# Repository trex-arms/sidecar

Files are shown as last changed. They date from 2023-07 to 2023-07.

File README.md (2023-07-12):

# T.REX ARMS Sidecar Project

The [T.REX ARMS Sidecar Holster](https://www.trex-arms.com/store/trex-arms-sidecar-holster/) is designed to be modular and extendable.  This repository contains resources that should be enough for anyone to design, manufacture, and sell their Sidecar accessories.  These files are licensed under the [MIT license](https://choosealicense.com/licenses/mit/).

## [Spine System](Spine)

The T.REX ARMS Sidecar hinges on its Spine System.  The Sidecar Spine System was developed with open-source capabilities in mind, since the Spine System is a design that combines the best aspects of both rigid and flexible Sidecar-style holsters. It allows rotation on one axis, which provides comfort, but is extremely rigid on all others, for better concealment. Furthermore, the integrated hinge is simpler, sleeker, and far more modular than other existing connector options.

The design is built around as many off-the-shelf tools and parts as possible, both to support end users and other manufacturers. For example, the hinge pin has a diameter of 0.25″ and the hinge teeth are 0.25″ with 0.25″ gaps. Individual Kydex attachments can be made with hand tools, and the Spine also interfaces well with plastic parts, like the [T.REX Raptor Wing](https://www.trex-arms.com/store/sidecar-raptor-wing-attachment/), or certain textiles, like the biothane [T.REX Tourniquet Holder](https://www.trex-arms.com/store/sidecar-tourniquet-attachment/).

Included are some prints showing all the dimensions in the Sidecar Spine standard that our holsters will be held to, and some 3D files of different tools used in holster manufacture.

## Accessories

We have had excellent results printing these accessories using PLA+ filament on FDM printers like the Ender 3, eSUN’s Hard-Tough resin on SLA printers like the Elgoo Mars line, and having them printed in nylon by professional printers like MK Machining.

### [Dual Wield Adapter](DualWieldAdapter)

If you would like to carry and fire two guns whilst jumping through the air, you would need two sidecar holsters connected together with exactly the right amount of separation for pistol optics and exactly the right amount of angle for a quick draw.

### [Extender](Extender)

One of the best ways to expand your Sidecar’s comfort and concealability might be to literally expand its width. A number of users have discovered that extending the distance between the holster and mag carrier can improve comfort and stability for certain body types.

Since there are many different ways in which you might want to do this, we're including three different widths of file type, as well as a few previous versions.

If you make one of these, you will also need an additional pin to assemble it. The Sidecar Spine System will work with almost any 0.25” rod, including standard hinge pins, but you can get extras from us [here](https://www.trex-arms.com/store/sidecar-spine-replacement-hardware/).

### [Wing](Spine/Wing)

You know, [one of these](https://www.trex-arms.com/store/sidecar-raptor-wing-attachment/). But there's also an angled one that lets you fold the clips back over the holster for a smaller footprint. These wings are also the ideal starting point for any new adapters designed to connect the spine system to any mounting hardware.

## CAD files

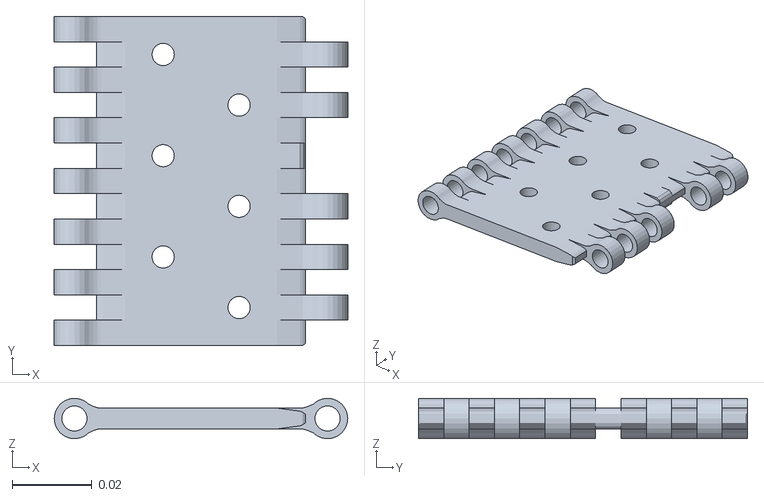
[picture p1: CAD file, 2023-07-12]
Extender/FullExtender25.stl
0.0737 x 0.0826 x 0.0102

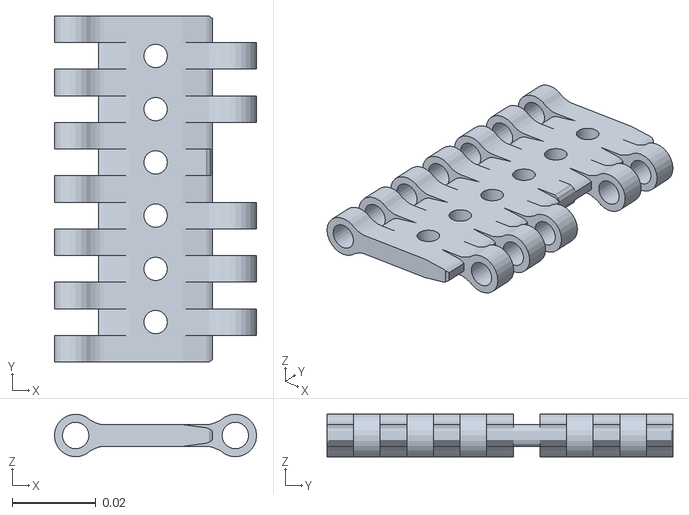
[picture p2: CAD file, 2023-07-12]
Extender/FullExtender15.stl
0.0483 x 0.0826 x 0.0102

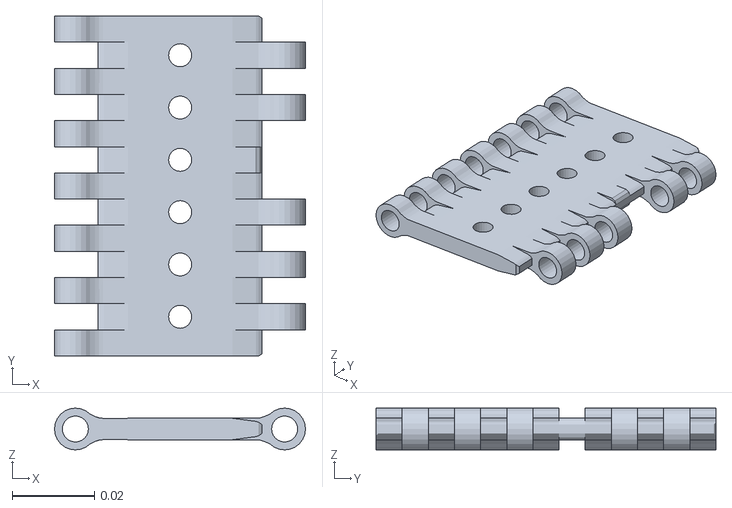
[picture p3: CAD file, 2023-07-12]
Extender/FullExtender20.stl
0.061 x 0.0826 x 0.0102

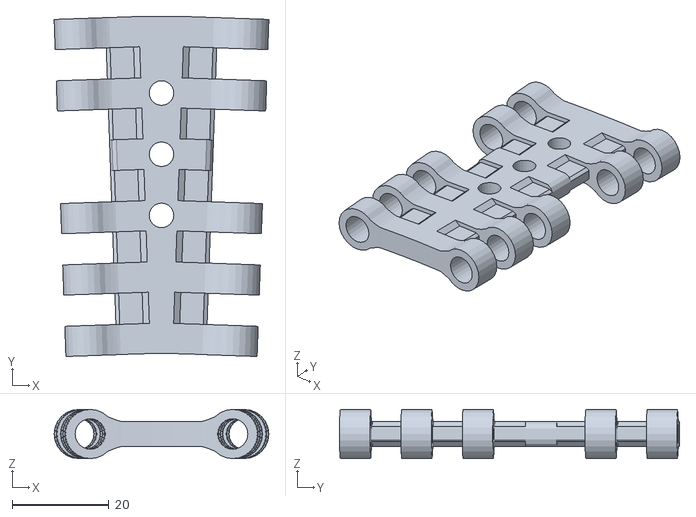
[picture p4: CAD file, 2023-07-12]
DualWieldAdapter/DualWieldAdapterV2.stl
44.4 x 70.3 x 10.2

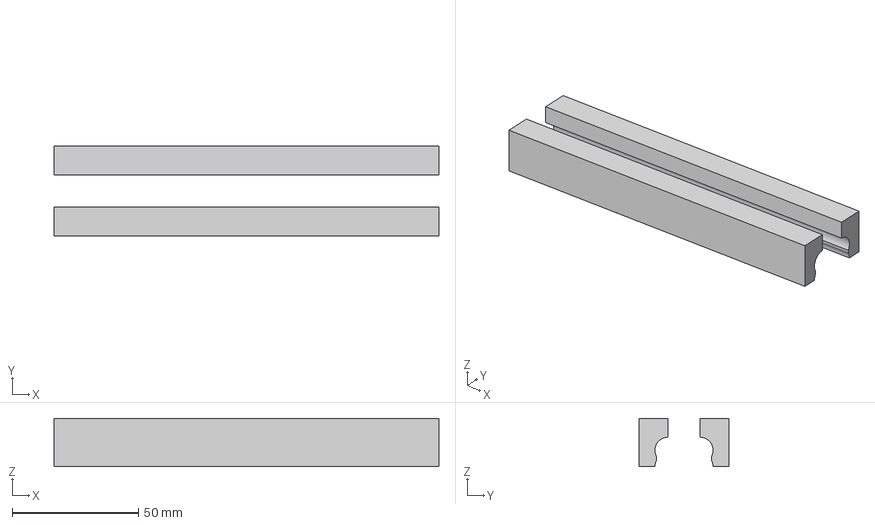
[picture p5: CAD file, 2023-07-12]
Spine/Sidecar Spine Clamp Halves.step
152.4 x 35.7 x 19.0 mm

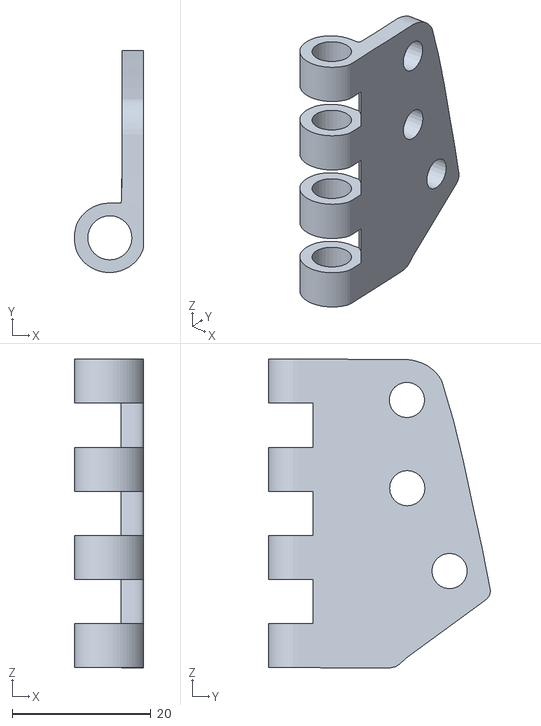
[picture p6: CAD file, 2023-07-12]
Spine/Wing/SidecarAngledWing.stl
10.0 x 32.0 x 44.5

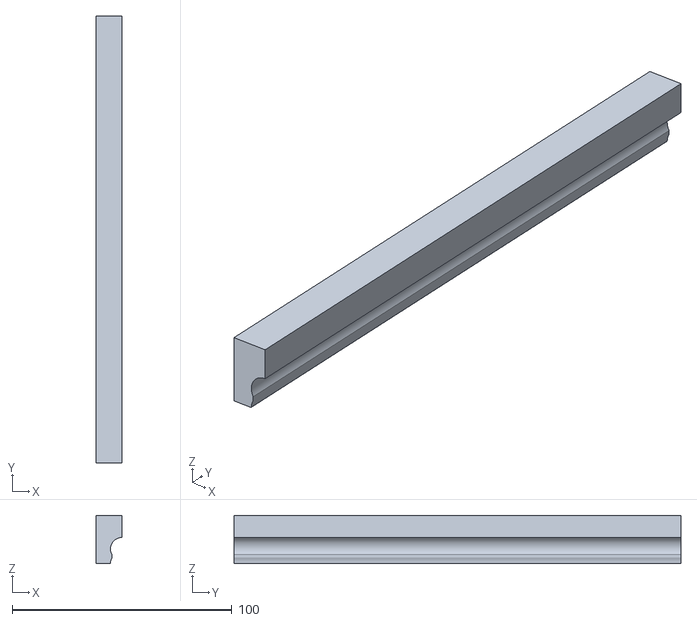
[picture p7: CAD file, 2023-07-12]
Spine/SidecarSpineClamp.stl
11.9 x 203.2 x 22.0

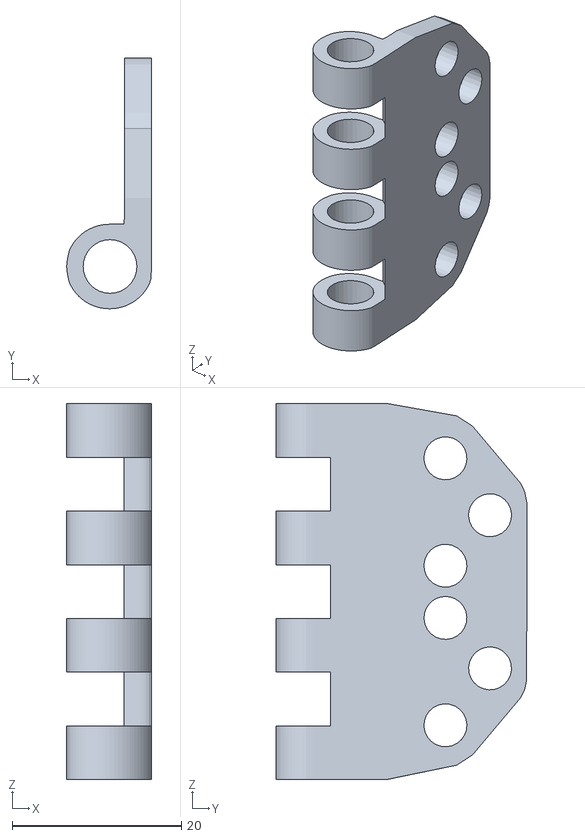
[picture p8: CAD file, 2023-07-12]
Spine/Wing/SidecarWingAdapter.stl
10.0 x 29.6 x 44.5

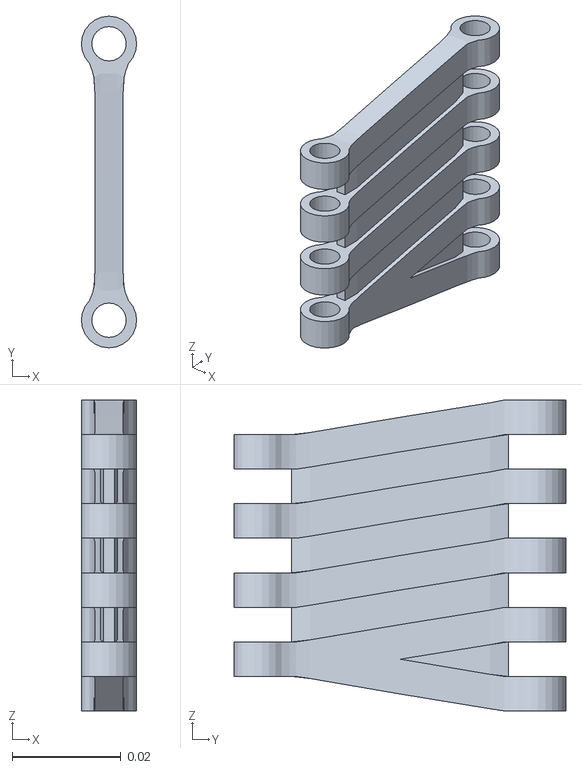
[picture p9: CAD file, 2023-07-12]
Extender/TinyBridge20.stl
0.0102 x 0.061 x 0.0571

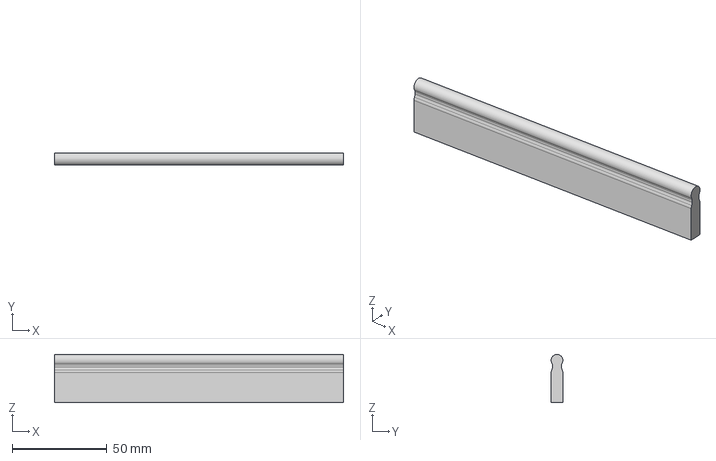
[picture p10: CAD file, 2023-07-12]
Spine/Sidecar Spine Sight Channel.step
152.4 x 6.22 x 25.4 mm

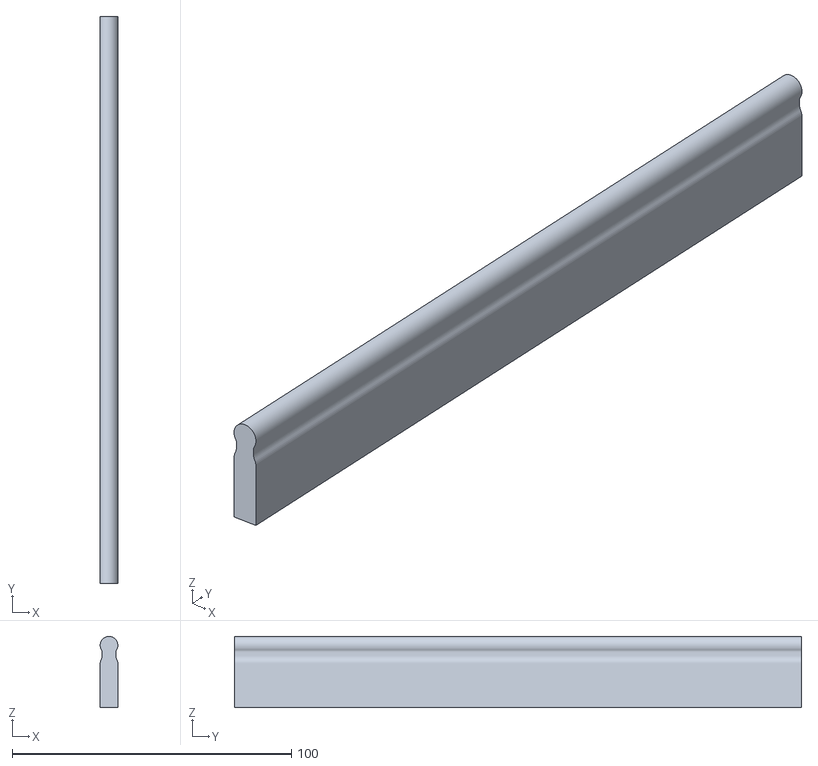
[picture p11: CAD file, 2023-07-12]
Spine/SidecarSpineChannel.stl
6.37 x 203.2 x 25.5

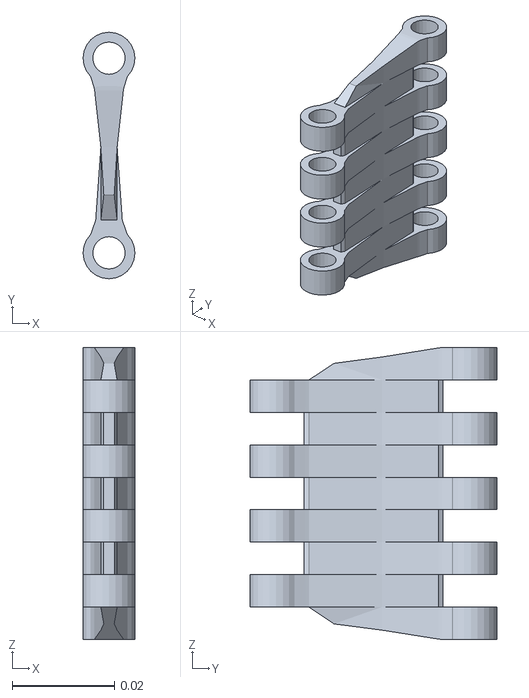
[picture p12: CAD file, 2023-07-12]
Extender/TinyBridge15.stl
0.0102 x 0.0483 x 0.0571

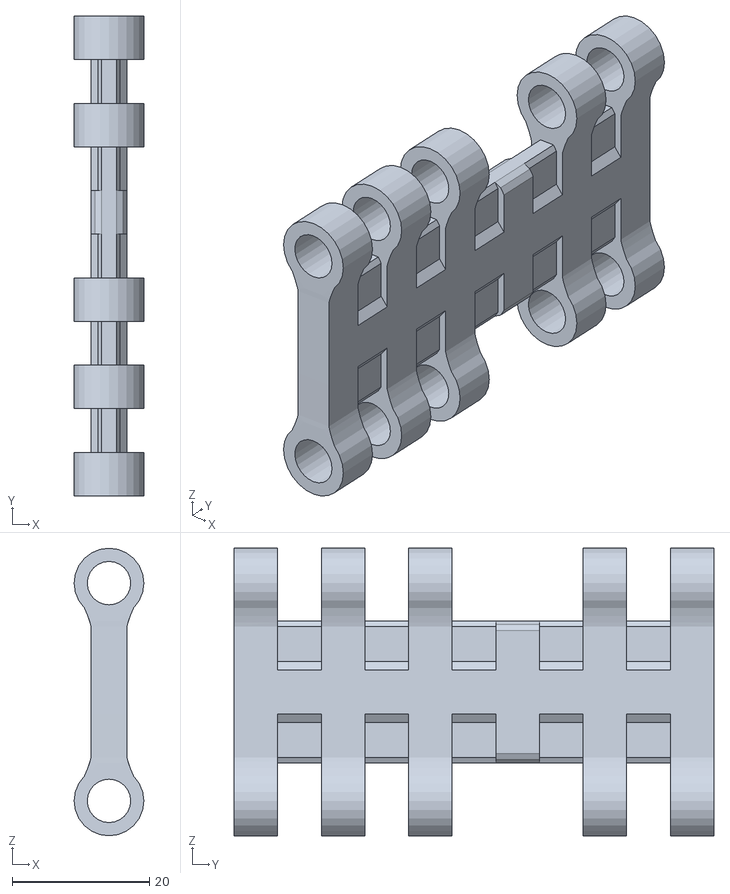
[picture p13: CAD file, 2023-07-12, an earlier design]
DualWieldAdapter/DualWieldAdapterV1.stl
10.2 x 69.8 x 41.8

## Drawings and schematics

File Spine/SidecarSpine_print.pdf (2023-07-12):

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

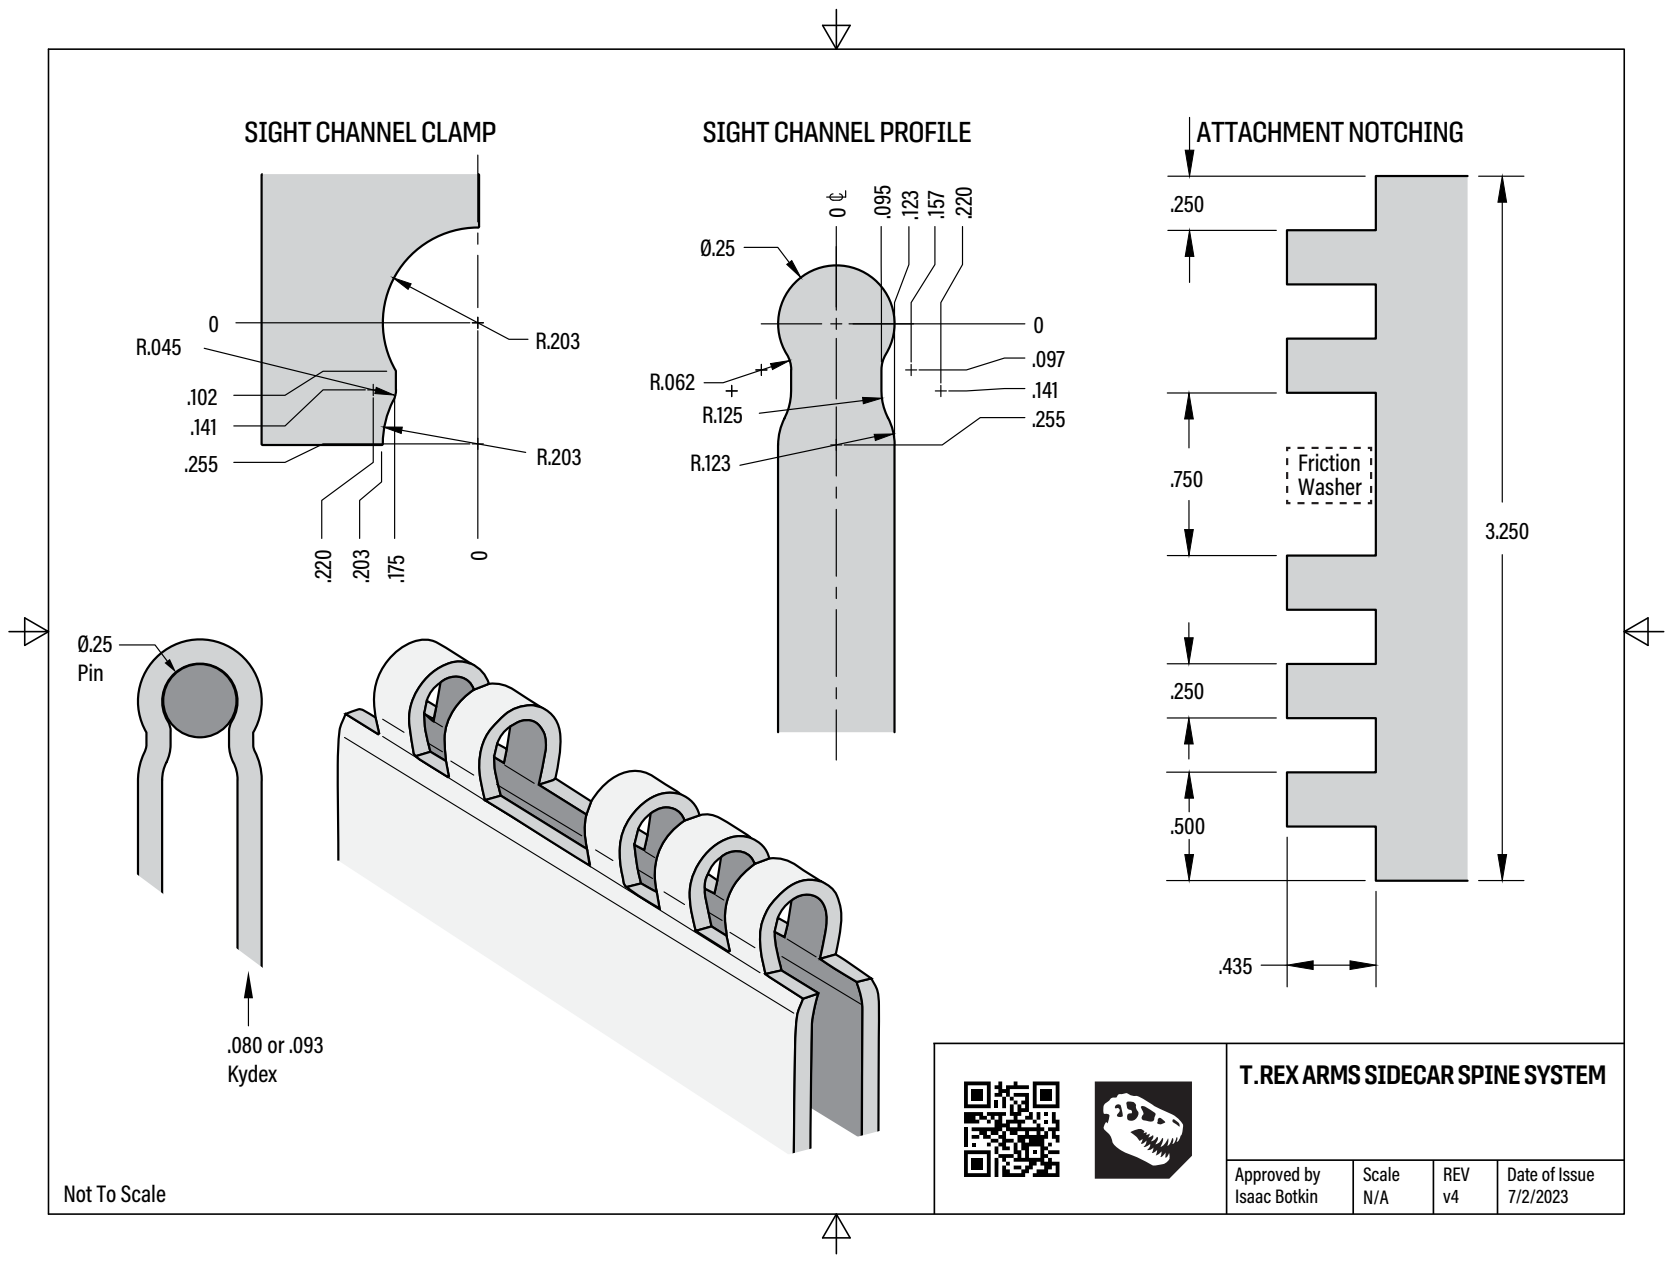
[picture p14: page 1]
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

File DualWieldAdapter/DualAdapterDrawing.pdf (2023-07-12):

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

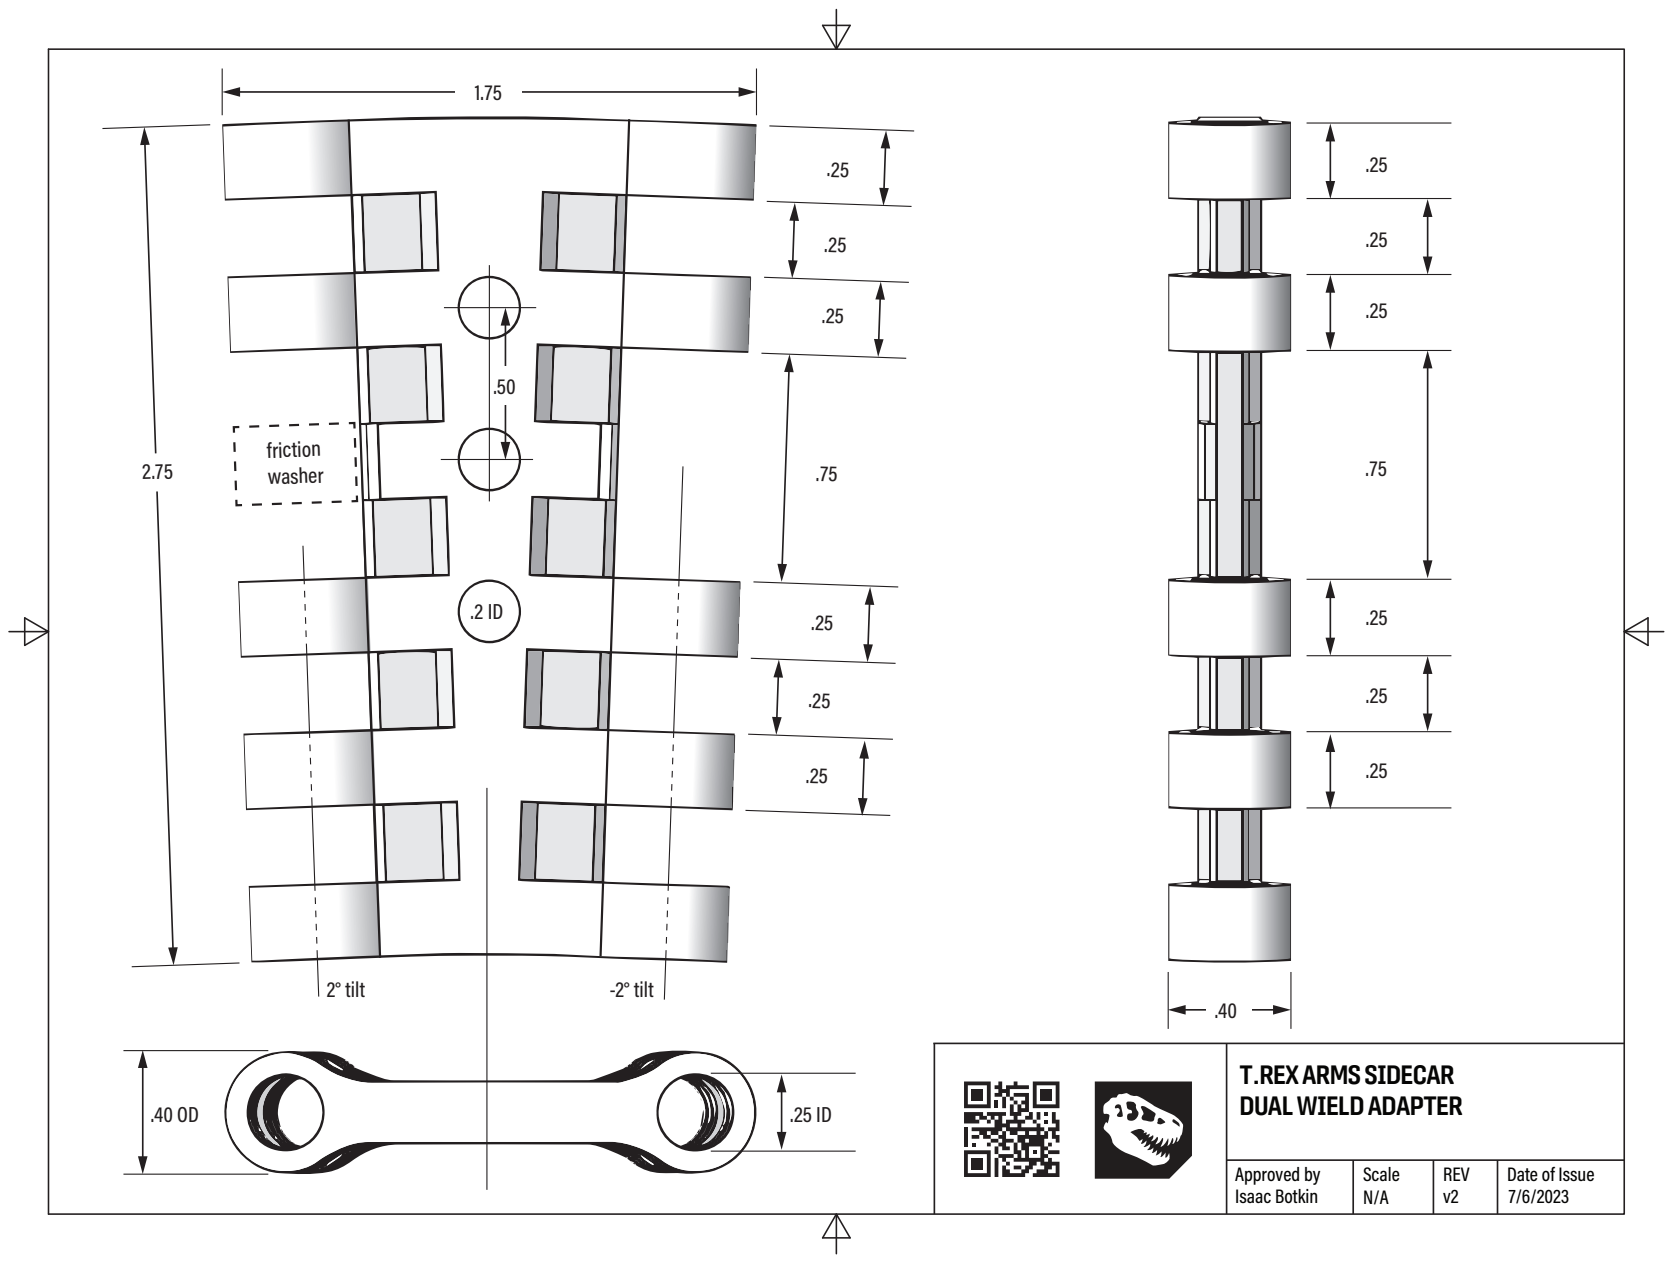
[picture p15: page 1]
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

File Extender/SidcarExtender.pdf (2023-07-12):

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

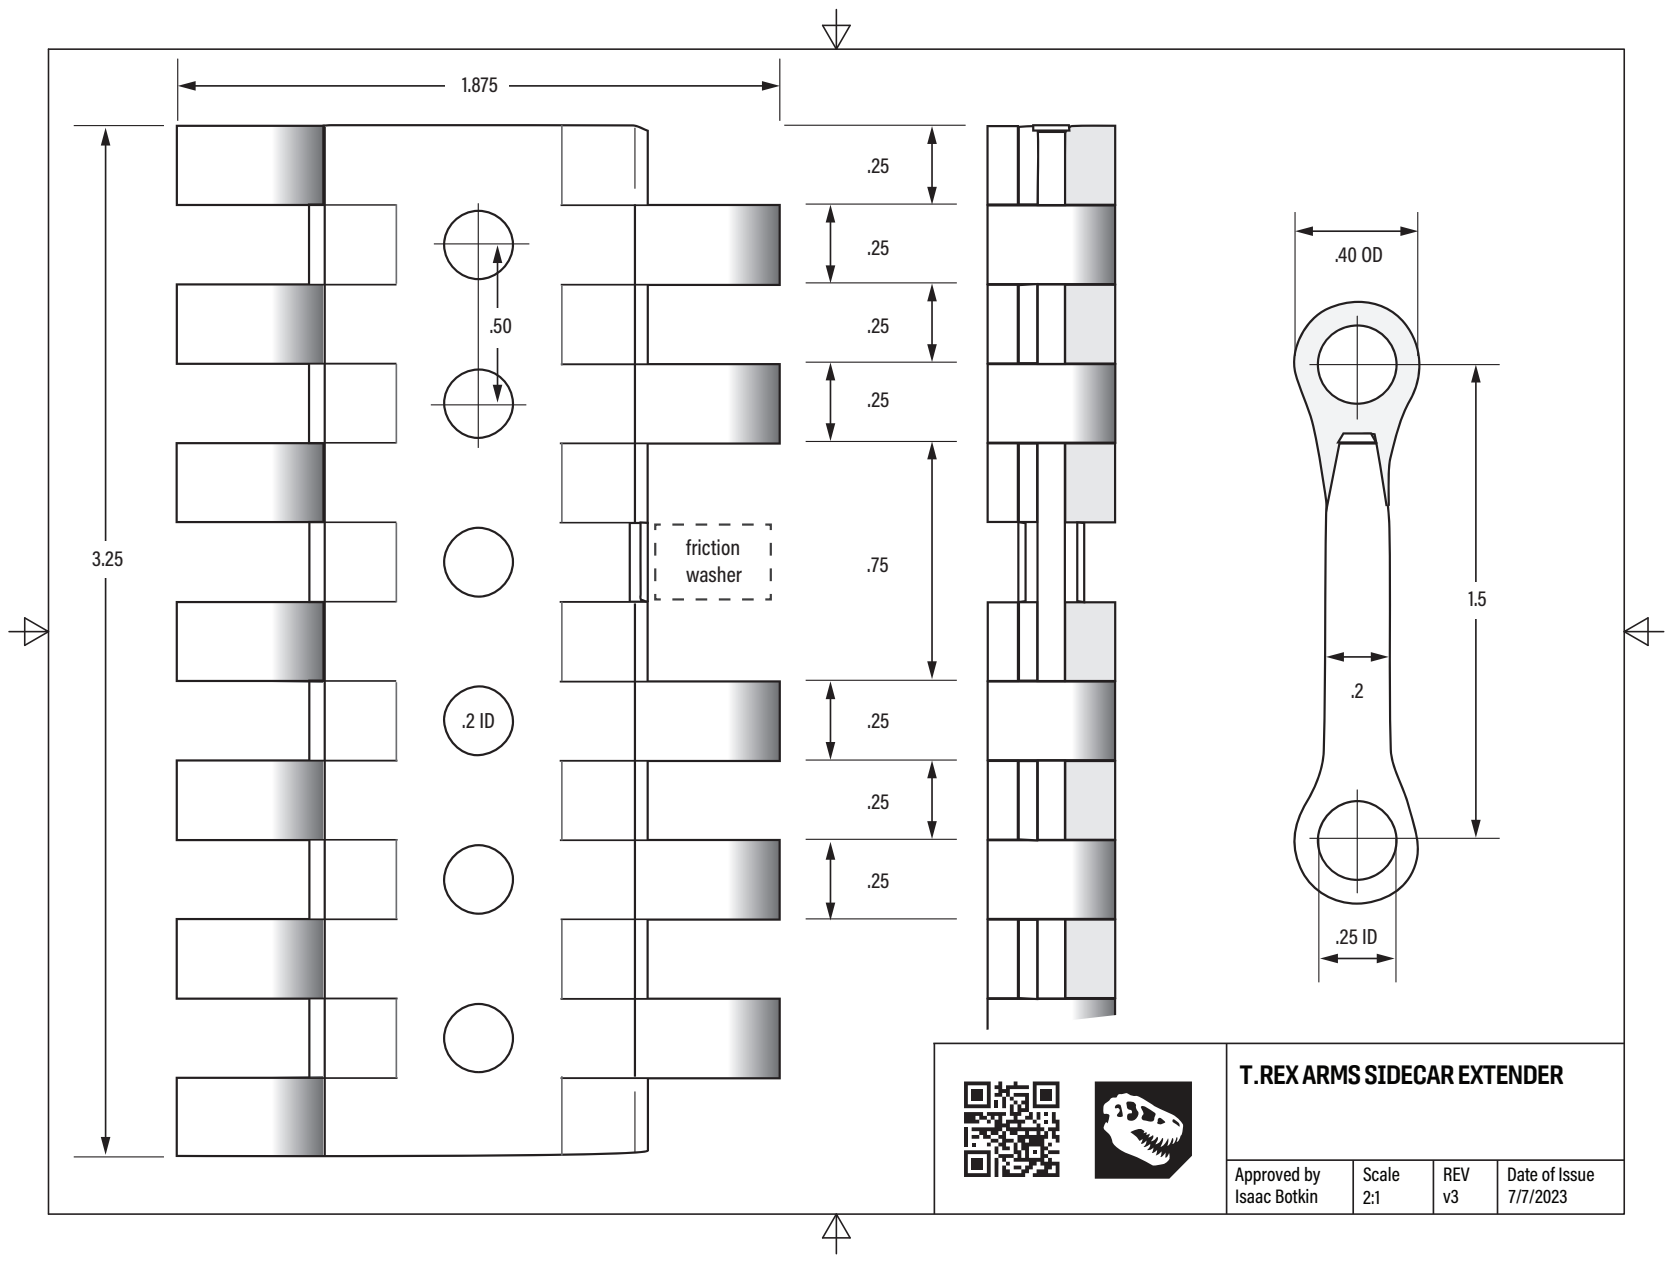
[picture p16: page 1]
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
